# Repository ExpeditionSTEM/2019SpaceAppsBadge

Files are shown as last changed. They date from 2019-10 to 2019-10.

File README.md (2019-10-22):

# 2019SpaceAppsBadge
PLEASE STAY TUNED FOR UPDATES!  I WILL GET THIS REPO UPDATED BY 10/29.

A description of the 2019 Space Apps Trophy made for the Huntsville Main Stage

LIST OF COMPONENTS:

CUSTOM:

Custom Printed Circuit Board (PCB) - Designed by Andrew Denio. Produced by JLCPCB.com See "EAGLE" folder for files.

ATTINY 85-20PU Microcontroller 8 pin DIP: https://www.amazon.com/gp/product/B06W9JBJJ6

SSD1306 128x32 pixel i2c OLED Display https://www.amazon.com/gp/product/B07WHVYWXS/

3xAAA Enclosed Battery Case https://www.amazon.com/gp/product/B07M8RV9DC

MISC:

Photoresistor (Light Sensor) 5 mm GM5539 5539 https://www.amazon.com/dp/B01N7V536K

Slide Switch 3 Pin 2 Position SPDT with PCB Panel for Arduino 0.5 Amp, 50V DC, 2 mm https://www.amazon.com/gp/product/B079D58DB3/

FROM JLCPCB (mounted through SMT assembly):

WS2812B-V3 - 5050 LIGHT EMITTING DIODE (LED) RED/GREEN/BLUE SMD

8 pin Female Header to re-flash ATTINY chip

FOR 'THROUGH-HOLE' BOARD:

470 OHM 1/4 Watt resistor

10 KOHM 1/4 Watt resistor

6mm x 6mm Tactile Buttons

10uF 25V Capacitor

FOR 'SMD' BOARD:

TACTILE SWITCHES SPST 5.10MM X 5.10MM 0.40MM 50MA @ 12VDC SMD

Multilayer Ceramic Capacitor - SMD/SMT 10UF 25V 0805 ROHS

CHIP RESISTOR - SURFACE MOUNT 10KOHMS ±1% 1/8W 0805 ROHS

CHIP RESISTOR - SURFACE MOUNT 470OHMS ±1% 1/8W 0805 ROHS

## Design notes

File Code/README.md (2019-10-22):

This folder contains the Demo Sketch used during the 2019 Space Apps Huntsville event as well as the required libraries

The "ATTiny Core" zip file includes the Tiny NeoPixel Library

The "LCD" assistant is used to convert a bitmap to a hex table for Arduino.

The "ozoled-oled-display-096-i2c-driver-library-master.zip" library has more example for the OLED display

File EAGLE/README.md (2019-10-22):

This folder contains the Eagle and Gerber files for the Space Apps badge

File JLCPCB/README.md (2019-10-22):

This folder contains the files needed for SMT Assembly from JLCPCB.com   Build of Materials and Mounting Positions.

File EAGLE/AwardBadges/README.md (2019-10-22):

This folder contains all of the files for the 10 different award badges given out on Sunday, October 21, 2019 at Space Apps Huntsville.  

Electrically, they are all the same.  The only difference is the screen printed layer to list what type of award the badge has been given.

These badges are also electrically the same as the "MainBadgeSMD."

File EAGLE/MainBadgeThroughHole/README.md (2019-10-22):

This badge is the non-assembled version.  I will create a YouTube video at some point on how to assemble this badge.

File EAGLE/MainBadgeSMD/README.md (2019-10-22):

This is the badge that was 'fully' assembled.  Most of the badge was assembled by JLCPCB, but some components were hand soldered/mounted.

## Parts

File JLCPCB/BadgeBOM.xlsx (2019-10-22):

Comment | Designator | Footprint | LCSC Part #（optional）
10uF | C1 | 0805 | C15850
10KO | R2 | 0805 | C17414
470O | R1 | 0805 | C17710
NEOPIXEL5050 | NEO1 | LED-4_5050 | C114585
NEOPIXEL5050 | NEO2 | LED-4_5050 | C114585
NEOPIXEL5050 | NEO3 | LED-4_5050 | C114585
NEOPIXEL5050 | NEO4 | LED-4_5050 | C114585
NEOPIXEL5050 | NEO5 | LED-4_5050 | C114585
NEOPIXEL5050 | NEO6 | LED-4_5050 | C114585
NEOPIXEL5050 | NEO7 | LED-4_5050 | C114585
NEOPIXEL5050 | NEO8 | LED-4_5050 | C114585
NEOPIXEL5050 | NEO9 | LED-4_5050 | C114585
NEOPIXEL5050 | NEO10 | LED-4_5050 | C114585
BUTTON_B | BUTTON | SMD-SW-4_5.1x5.1x2.0 | C318884
BUTTON_A | RESET | SMD-SW-4_5.1x5.1x2.0 | C318884

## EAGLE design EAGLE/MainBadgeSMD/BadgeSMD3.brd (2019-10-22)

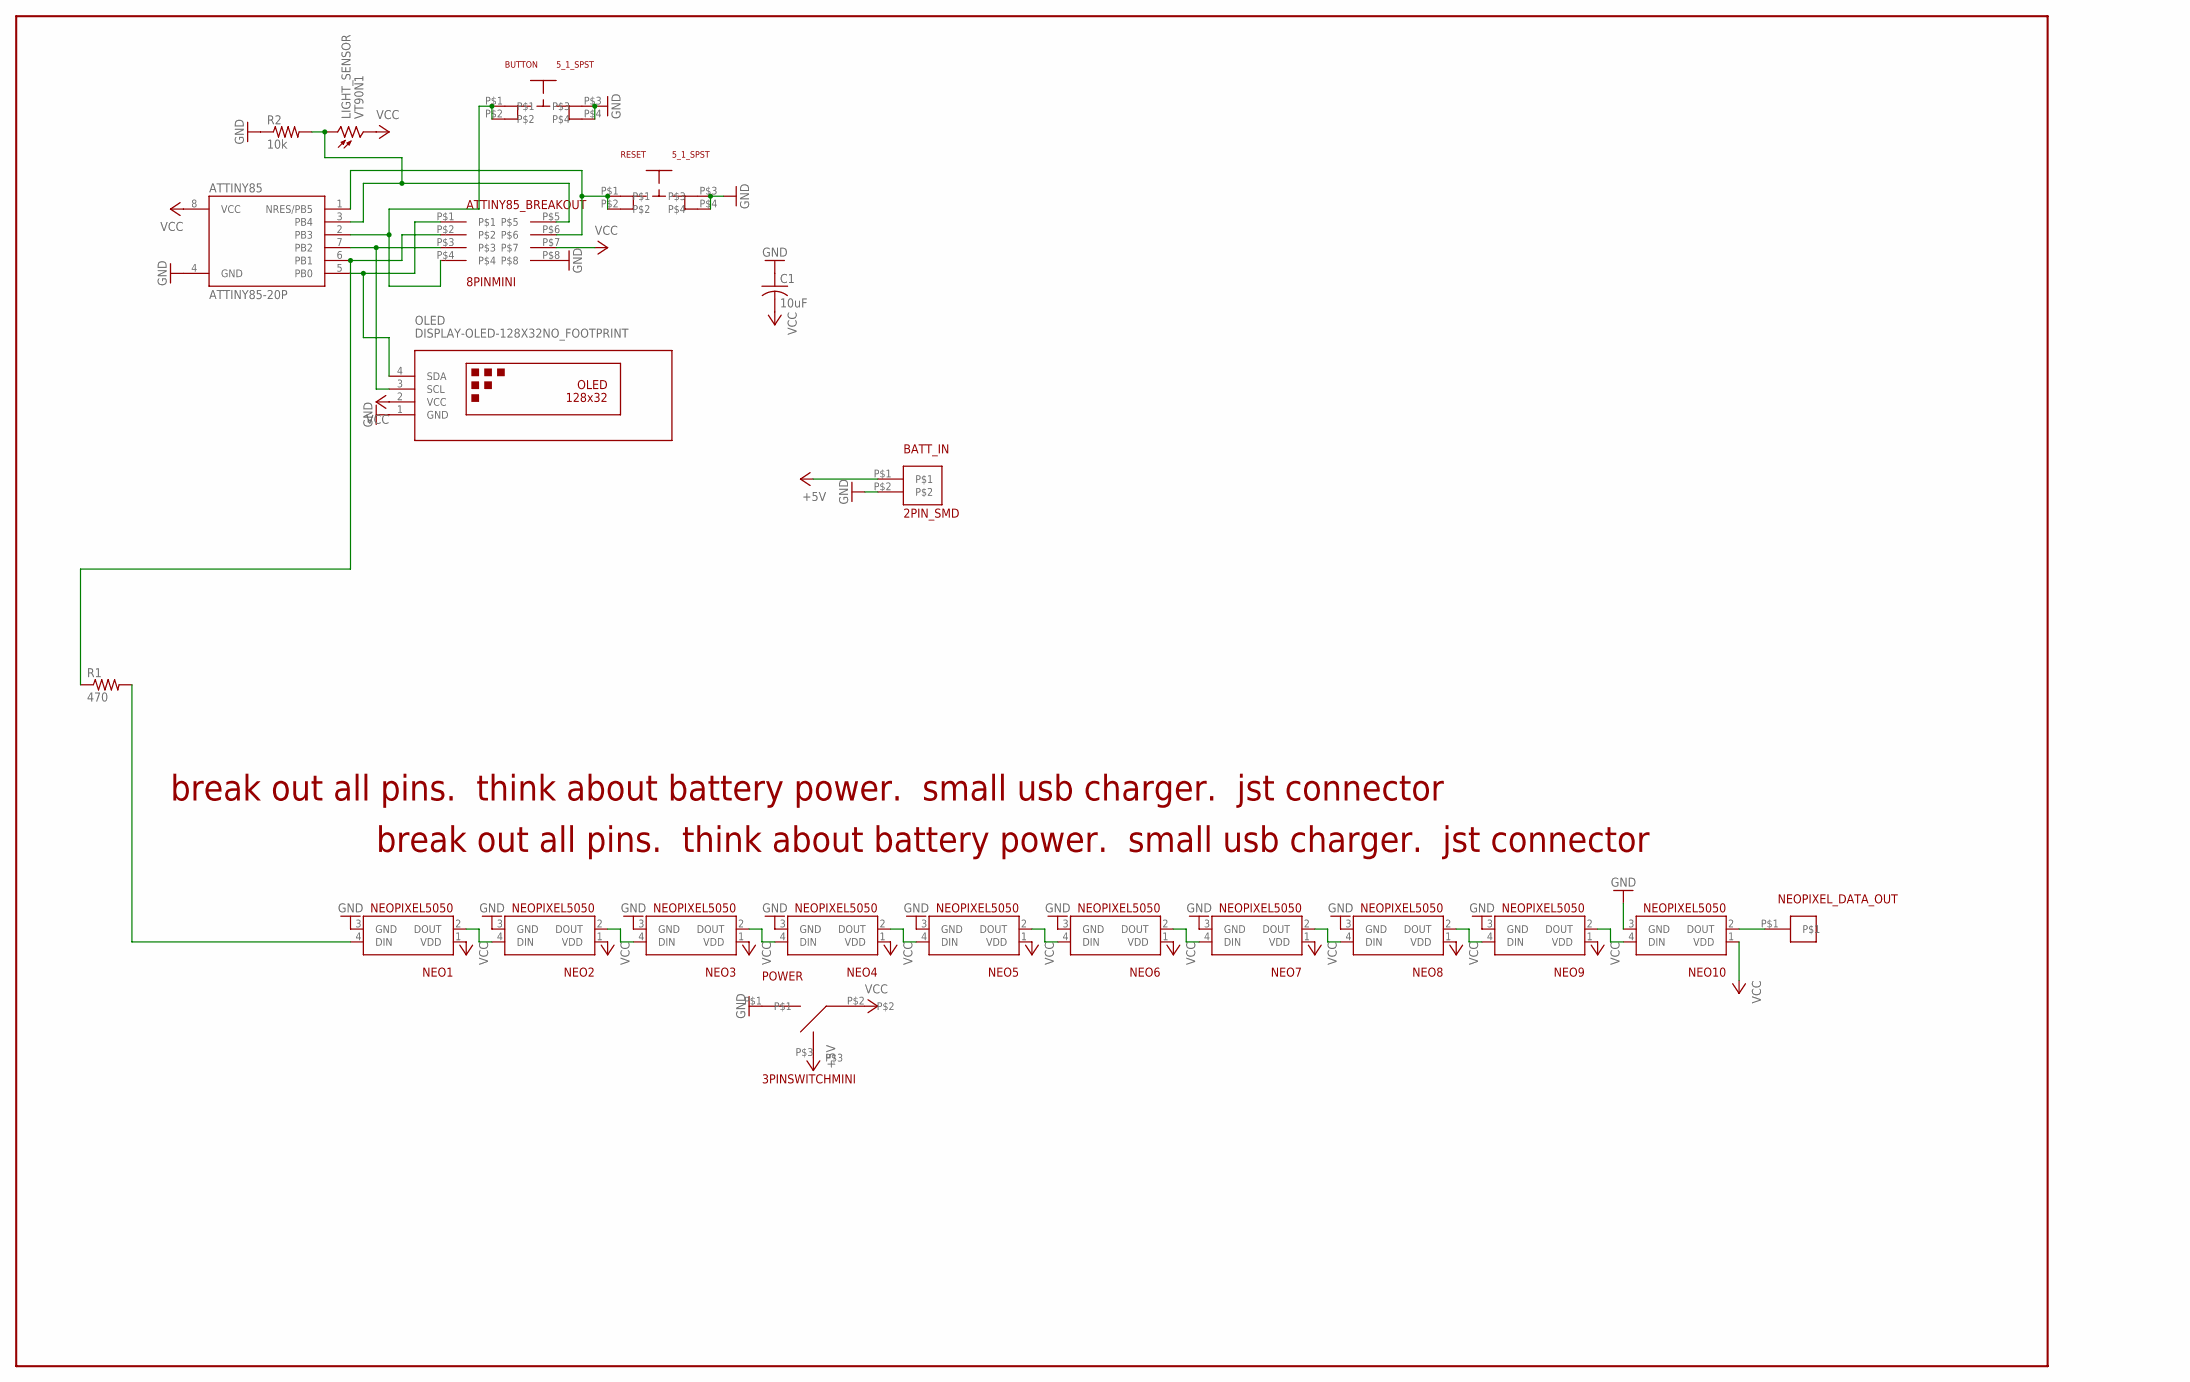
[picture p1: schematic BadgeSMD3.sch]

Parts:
ATTINY85: ATTINY85-20P; PDIP08_300MIL
ATTINY85_BREAKOUT: 8PINMINI
BATT_IN: 2PIN_SMD
BUTTON: 5_1_SPST
C1: 10uF; C0805
LIGHT_SENSOR: VT90N1; VT900
NEO1, NEO2, NEO3, NEO4, NEO5, NEO6, NEO7, NEO8, NEO9, NEO10: NEOPIXEL5050
NEOPIXEL_DATA_OUT: 1PINMINI
OLED: DISPLAY-OLED-128X32NO_FOOTPRINT; DISPLAY-OLED-128X32_NO_FOOTPRINT
POWER: 3PINSWITCHMINI; 3PINMINI
R1: 470; M0805
R2: 10k; M0805
RESET: 5_1_SPST

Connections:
+5V: BATT_IN.P$1, POWER.P$3
GND: ATTINY85.4 (GND), ATTINY85_BREAKOUT.P$8, BATT_IN.P$2, BUTTON.P$3, BUTTON.P$4, C1.1, NEO1.3 (GND), NEO2.3 (GND), NEO3.3 (GND), NEO4.3 (GND), NEO5.3 (GND), NEO6.3 (GND), NEO7.3 (GND), NEO8.3 (GND), NEO9.3 (GND), NEO10.3 (GND), OLED.1 (GND), POWER.P$1, R2.1, RESET.P$3, RESET.P$4
unnamed: ATTINY85.5 (PB0), ATTINY85_BREAKOUT.P$1, OLED.4 (SDA)
unnamed: NEO1.4 (DIN), R1.2
unnamed: ATTINY85.7 (PB2), ATTINY85_BREAKOUT.P$3, OLED.3 (SCL)
unnamed: ATTINY85.2 (PB3), ATTINY85_BREAKOUT.P$4, BUTTON.P$1, BUTTON.P$2
unnamed: ATTINY85.3 (PB4), ATTINY85_BREAKOUT.P$5, LIGHT_SENSOR.1, R2.2
unnamed: ATTINY85.1 (NRES/PB5), ATTINY85_BREAKOUT.P$6, RESET.P$1, RESET.P$2
unnamed: NEO1.2 (DOUT), NEO2.4 (DIN)
unnamed: ATTINY85.6 (PB1), ATTINY85_BREAKOUT.P$2, R1.1
unnamed: NEO2.2 (DOUT), NEO3.4 (DIN)
unnamed: NEO3.2 (DOUT), NEO4.4 (DIN)
unnamed: NEO4.2 (DOUT), NEO5.4 (DIN)
unnamed: NEO5.2 (DOUT), NEO6.4 (DIN)
unnamed: NEO6.2 (DOUT), NEO7.4 (DIN)
unnamed: NEO7.2 (DOUT), NEO8.4 (DIN)
unnamed: NEO8.2 (DOUT), NEO9.4 (DIN)
unnamed: NEO9.2 (DOUT), NEO10.4 (DIN)
unnamed: NEO10.2 (DOUT), NEOPIXEL_DATA_OUT.P$1
VCC: ATTINY85.8 (VCC), ATTINY85_BREAKOUT.P$7, C1.2, LIGHT_SENSOR.2, NEO1.1 (VDD), NEO2.1 (VDD), NEO3.1 (VDD), NEO4.1 (VDD), NEO5.1 (VDD), NEO6.1 (VDD), NEO7.1 (VDD), NEO8.1 (VDD), NEO9.1 (VDD), NEO10.1 (VDD), OLED.2 (VCC), POWER.P$2

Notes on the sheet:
break out all pins. think about battery power. small usb charger. jst connector

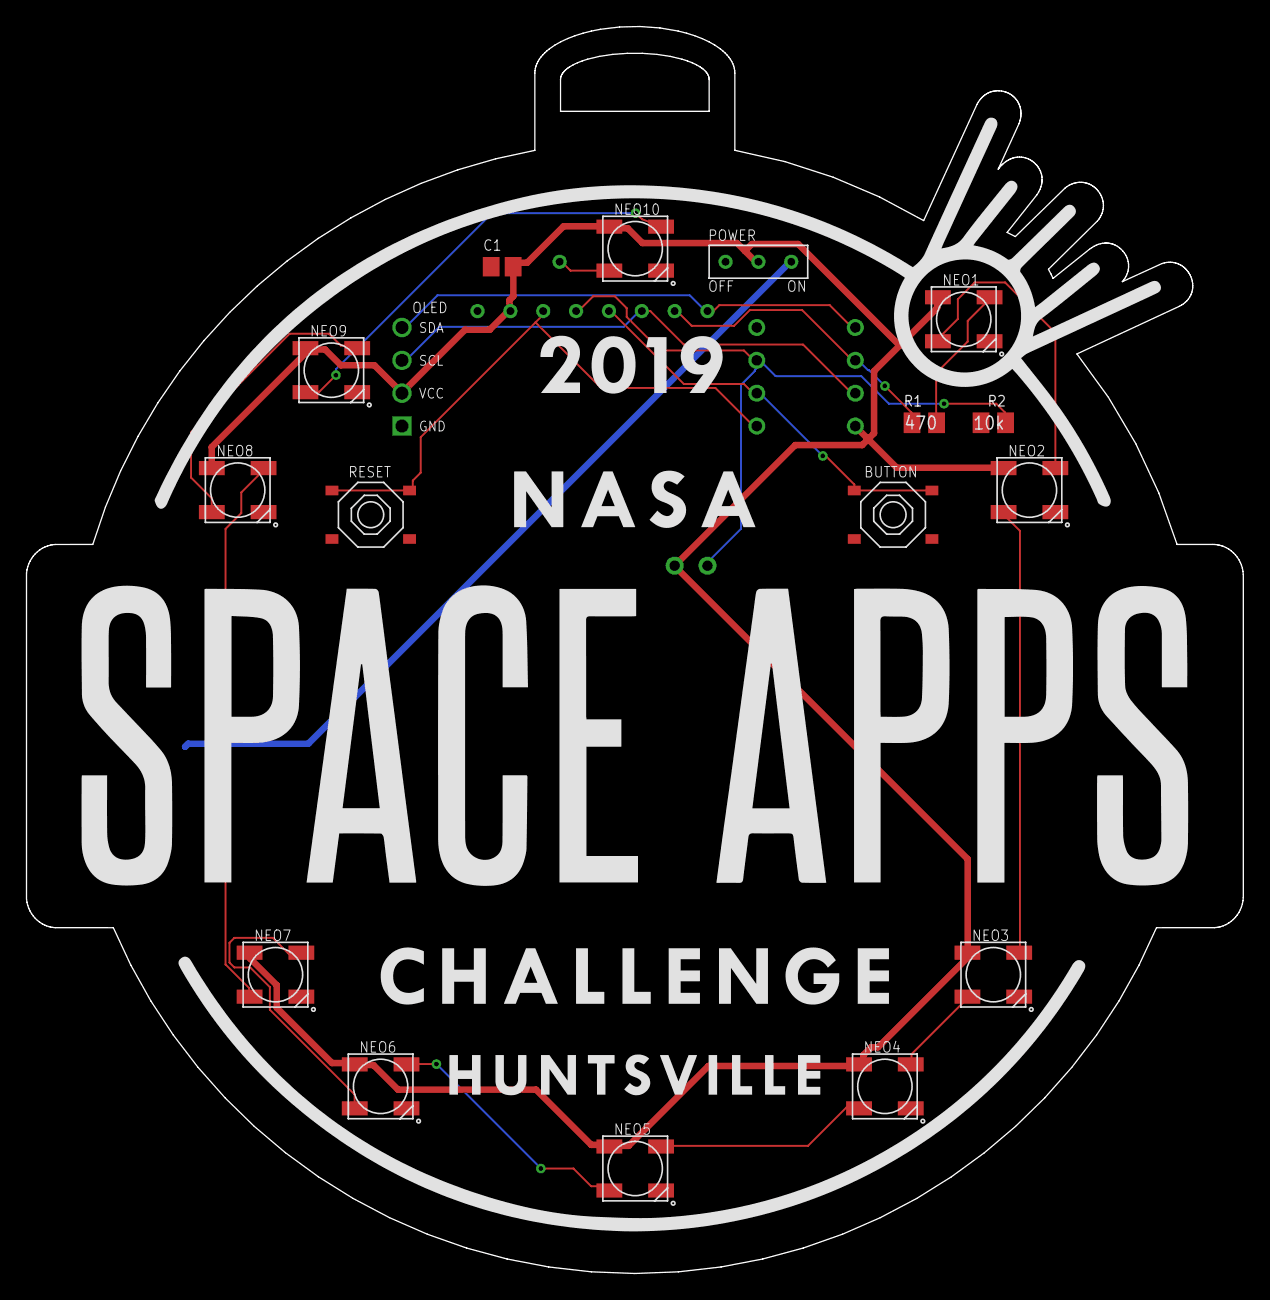
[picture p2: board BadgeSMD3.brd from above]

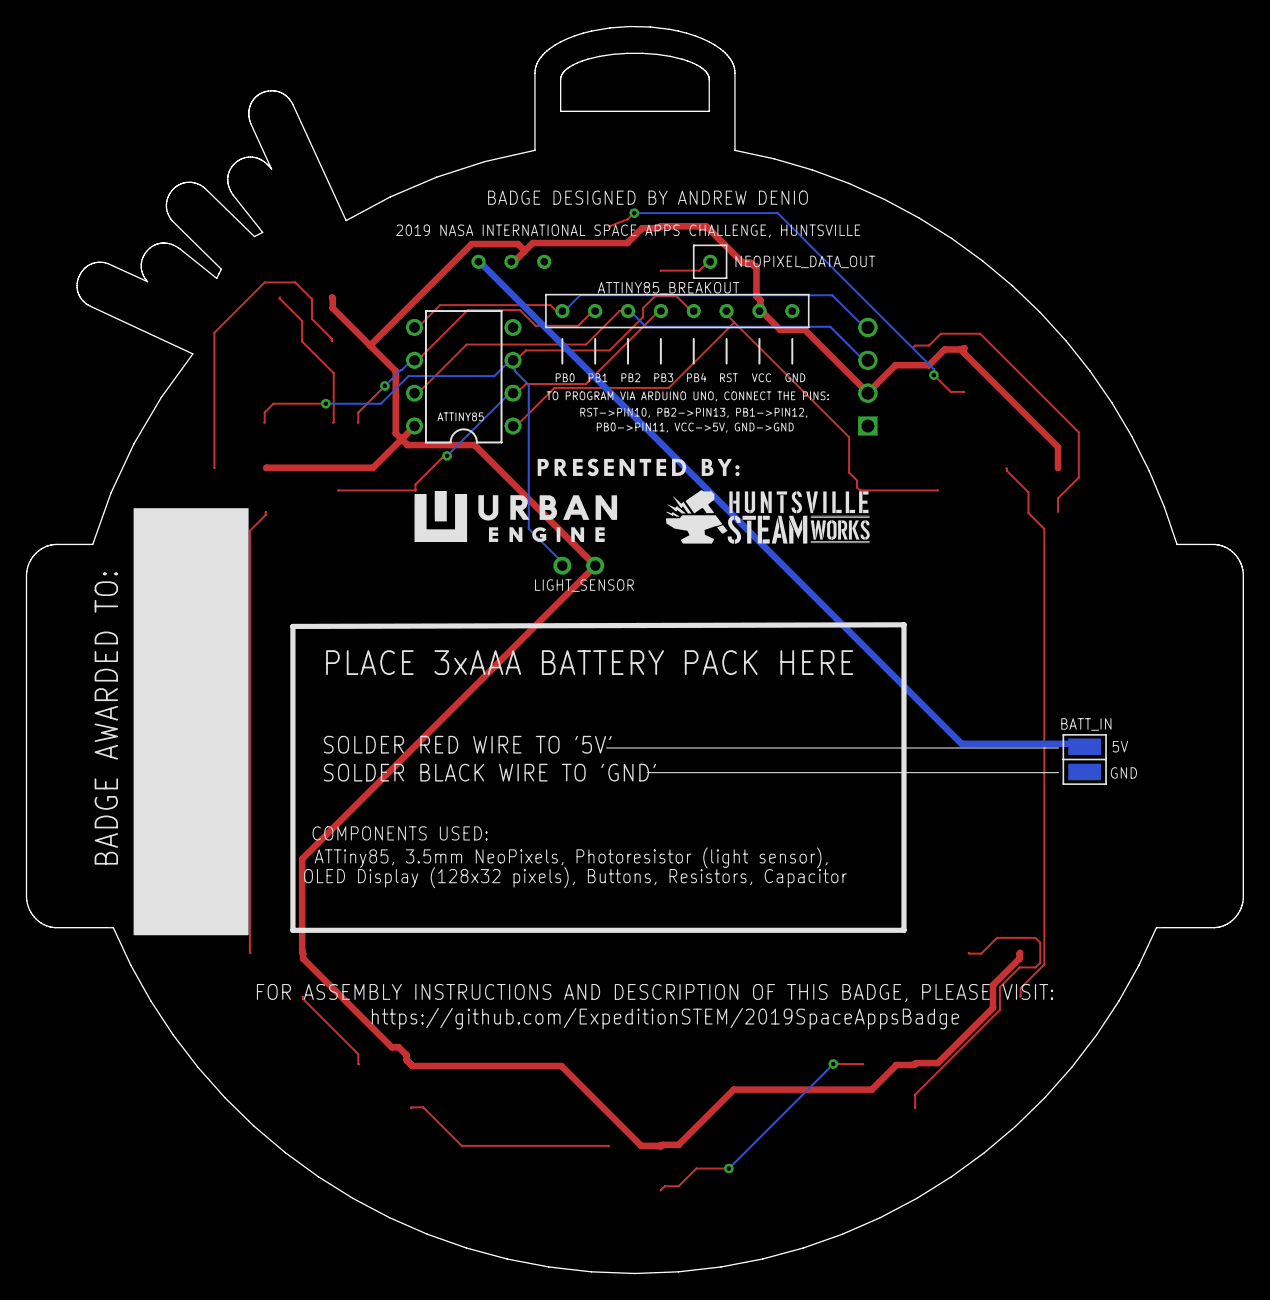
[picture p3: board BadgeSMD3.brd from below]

Board: 2 copper layers, 94.1 x 96.4 mm, 22 parts (5 on the bottom side), 20 nets.

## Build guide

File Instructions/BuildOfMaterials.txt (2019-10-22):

2019 Space Apps Through-Hole Badge
Build of Materials

Because some of these components are really small, it would be in everyone's financial interest to try and source these parts as a team, because you only need a few of each.
The links below are suggestions and you may be able to find a better deal somewhere else.

1x Custom Printed Circuit Board (PCB).  
Provided at Space Apps

1x ATTINY 85-20PU Microcontroller 8 pin DIP (comes in 5-pack): 
https://www.amazon.com/gp/product/B06W9JBJJ6

1x SSD1306 128x32 pixel i2c OLED Display (comes in 2-pack) 
https://www.amazon.com/gp/product/B07WHVYWXS/

1x 3xAAA Enclosed Battery Case (comes in 6 pack) 
https://www.amazon.com/gp/product/B07M8RV9DC

1x  Photoresistor (Light Sensor) 5 mm GM5539 5539 (30 pack) 
https://www.amazon.com/dp/B01N7V536K

1x Slide Switch 3 Pin 2 Position SPDT with PCB Panel for Arduino 0.5 Amp, 50V DC, 2 mm (50 pack) 
https://www.amazon.com/gp/product/B079D58DB3/

10x WS2812B- 5050 LIGHT EMITTING DIODE (LED) RED/GREEN/BLUE SMD (NEOPIXELS)
https://www.amazon.com/ACROBOTIC-10-Pack-WS2812B-Arduino-Raspberry/dp/B07RYP2WVY/
https://www.amazon.com/Led-World-WS2812B-Individually-Addressable/dp/B00YC7ZXRM
https://www.adafruit.com/product/1655
https://www.adafruit.com/product/3094

1x 8 pin Female Header to Flash ATTINY chip 
https://www.amazon.com/Glarks-Straight-Connector-Assortment-Prototype/dp/B076GZXW3Z

1x 470 OHM 1/4 Watt resistor
https://www.amazon.com/AUSTOR-Resistors-Assortment-Resistor-Experiments/dp/B07BKRS4QZ/

1x 10 KOHM 1/4 Watt resistor
https://www.amazon.com/AUSTOR-Resistors-Assortment-Resistor-Experiments/dp/B07BKRS4QZ/

2x 6mm x 6mm Tactile Buttons   
https://www.amazon.com/Momentary-Tactile-Button-Switch-black/dp/B0796QHL5Z/

1x 10uF 25V Capacitor
https://www.amazon.com/gp/product/B01MSQOX0Q/

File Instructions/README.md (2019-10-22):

INSTRUCTIONS

I have provided the Demo Code / sketch used during the 2019 Space Apps Huntsville event. 

I will upload a YouTube video of how to use the demo sketch on the trophy when I get a chance.

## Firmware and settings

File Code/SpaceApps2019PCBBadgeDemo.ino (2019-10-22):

////////////////////////////////////////////////////////////////
//////////  2019 SPACE APPS HUNTSVILLE - PCB BADGE DEMO CODE - BY ANDREW DENIO 
////////////////////////////////////////////////////////////////

/*
  THIS CODE WAS USED TO DEMO THE BADGE FOR 2019 SPACE APPS CHALLENGE EVENT IN HUNTSVILLE.

  ALL LIBRARIES FOR COMPONENTS WILL BE INCLUDED IN GITHUB LINK, SO FEEL FREE TO TINKER AROUND!
  https://github.com/ExpeditionSTEM/2019SpaceAppsBadge

  LIBRARIES FOR NEOPIXELS WERE DERIVED FROM LIBRARIES BY ADAFRUIT

  Adafruit invests time and resources providing this open source code,
  please support Adafruit and open-source hardware by purchasing
  products from Adafruit!
  Written by Limor Fried/Ladyada for Adafruit Industries.
  MIT license, all text above must be included in any redistribution
  
 */


////////////////////////////////////////////////////////////////
//////////  ATTINY 85 PINOUT
////////////////////////////////////////////////////////////////

 
/*
  
  GND - BATTERY NEGATIVE TERMINAL
  VCC - BATTERY POSITIVE TERMINAL
  PBO - I2C BUS - SDA
  PB1 - NEOPIXEL OUT
  PB2 - I2C BUS - SCL
  PB3 - BUTTON INPUT
  PB4 - LIGHT SENSOR INPUT
  PB5 - RESET BUTTON
  
 */


////////////////////////////////////////////////////////////////
//////////  VARIABLES AND LIBRARIES
////////////////////////////////////////////////////////////////

#include "TinyWireM.h" // USED FOR I2C CAPABILITIES
#include "TinyOzOLED.h" // USED FOR THE SSD1306 OLED SCREEN

#include <tinyNeoPixel_Static.h>  // USED FOR NEOPIXELS
#define PIN 1
// Parameter 1 = number of pixels in strip
// Parameter 2 = Arduino pin number (most are valid)
// Parameter 3 = pixel type flags, add together as needed:
//   NEO_GRB     Pixels are wired for GRB bitstream (most NeoPixel products)
//   NEO_RGB     Pixels are wired for RGB bitstream (v1 FLORA pixels, not v2)
// Parameter 4 = array to store pixel data in      
#define NUMPIXELS 10
// Since this is for the static version of the library, we need to supply the pixel array
// This saves space by eliminating use of malloc() and free(), and makes the RAM used for
// the frame buffer show up when the sketch is compiled.
byte pixels[NUMPIXELS * 3];
// When we setup the NeoPixel library, we tell it how many pixels, and which pin to use to send signals.
// Note that for older NeoPixel strips you might need to change the third parameter--see the strandtest
// example for more information on possible values. Finally, for the 4th argument we pass the array we
// defined above.
tinyNeoPixel strip = tinyNeoPixel(NUMPIXELS, PIN, NEO_GRB, pixels);
// IMPORTANT: To reduce NeoPixel burnout risk, add 1000 uF capacitor across
// pixel power leads, add 300 - 500 Ohm resistor on first pixel's data input
// and minimize distance between Arduino and first pixel.  Avoid connecting
// on a live circuit...if you must, connect GND first.


#define BUTTON_PIN   3    // Digital IO pin connected to the button.  This will be
                          // driven with a pull-up resistor so the switch should
                          // pull the pin to ground momentarily.  On a high -> low
                          // transition the button press logic will execute.

                          

#define LIGHT_SENSOR_PIN A2  // THIS IS PB4, BUT MUST LABEL IT A2 IN ORDER FOR THE ANALOG FUNCTIONS TO WORK
int lightSensorValue = 0;



//THIS IS THE BITMAP OUTPUT TO DISPLAY THE SPACE APPS LOGO ON STARTUP
const unsigned char spaceapps [] PROGMEM = {
0x00, 0x00, 0x00, 0x00, 
0x00, 0x00, 0x00, 0x00, 0x00, 0x00, 0x00, 0x00, 0x00, 0x00, 0x00, 0xC0, 0xF0, 0x18, 0x08, 0x0C,
0x08, 0x38, 0xF0, 0x00, 0x00, 0x00, 0x00, 0xF8, 0xF8, 0x18, 0x18, 0x18, 0x18, 0x18, 0xF0, 0x00,
0x00, 0x00, 0x00, 0x00, 0xE0, 0xF8, 0xF8, 0x80, 0x00, 0x00, 0x00, 0x00, 0x00, 0x00, 0xF0, 0x18,
0x08, 0x0C, 0x08, 0x18, 0xF0, 0x00, 0x00, 0x00, 0x00, 0xF8, 0xF8, 0x18, 0x18, 0x18, 0x18, 0x18,
0x00, 0x00, 0x00, 0x00, 0x00, 0x00, 0x00, 0x00, 0x00, 0x00, 0x00, 0x80, 0xF8, 0xF8, 0xE0, 0x00,
0x00, 0x00, 0x00, 0x00, 0x00, 0xF8, 0xF8, 0x18, 0x18, 0x18, 0x18, 0x18, 0xF0, 0xC0, 0x00, 0x00,
0x00, 0xF8, 0xF8, 0x18, 0x18, 0x18, 0x18, 0x18, 0xF0, 0x00, 0x00, 0x00, 0x00, 0xF0, 0xF8, 0x08,
0x08, 0x08, 0x18, 0xF8, 0x00, 0x00, 0x00, 0x00, 0x00, 0x00, 0x00, 0x00, 0x00, 0x00, 0x00, 0x00,
0x00, 0x00, 0x00, 0x00, 0x00, 0x00, 0x00, 0x00, 0x00, 0x00, 0x00, 0x0F, 0x3F, 0xE0, 0xC0, 0x80,
0x00, 0x00, 0x07, 0x00, 0x00, 0x00, 0x00, 0xFF, 0xFF, 0x80, 0x80, 0x80, 0x80, 0xC0, 0x7F, 0x00,
0x00, 0x00, 0x00, 0xE0, 0xFF, 0x01, 0x07, 0xFF, 0xC0, 0x00, 0x00, 0x00, 0x00, 0x00, 0xFF, 0x00,
0x00, 0x00, 0x00, 0x00, 0x07, 0x00, 0x00, 0x00, 0x00, 0xFF, 0xFF, 0x80, 0x80, 0x80, 0x00, 0x00,
0x00, 0x00, 0x00, 0x00, 0x00, 0x00, 0x00, 0x00, 0x00, 0x00, 0xC0, 0xFF, 0x03, 0x01, 0xFF, 0xF0,
0x00, 0x00, 0x00, 0x00, 0x00, 0xFF, 0xFF, 0x80, 0x80, 0x80, 0x80, 0xC0, 0xFF, 0x3F, 0x00, 0x00,
0x00, 0xFF, 0xFF, 0x80, 0x80, 0x80, 0x80, 0xC0, 0xFF, 0x06, 0x00, 0x00, 0x00, 0x3F, 0x7F, 0xC0,
0x80, 0x00, 0x00, 0x07, 0x00, 0x00, 0x00, 0x00, 0x00, 0x00, 0x00, 0x00, 0x00, 0x00, 0x00, 0x00,
0x00, 0x00, 0x00, 0x00, 0x00, 0x00, 0x00, 0x00, 0x00, 0x00, 0x00, 0xE0, 0xE0, 0x00, 0x01, 0x03,
0x07, 0x1C, 0xF8, 0x00, 0x00, 0x00, 0x00, 0xFF, 0xFF, 0x01, 0x01, 0x01, 0x01, 0x00, 0x00, 0x00,
0x00, 0x00, 0xF0, 0xFF, 0x00, 0x00, 0x00, 0x07, 0xFF, 0xC0, 0x00, 0x00, 0x00, 0x00, 0xFF, 0x00,
0x00, 0x00, 0x00, 0x00, 0xE0, 0x00, 0x00, 0x00, 0x00, 0xFF, 0xFF, 0x01, 0x01, 0x01, 0x00, 0x00,
0x00, 0x00, 0x00, 0x00, 0x00, 0x00, 0x00, 0x00, 0x00, 0xC0, 0xFF, 0x03, 0x00, 0x00, 0x01, 0xFF,
0xF0, 0x00, 0x00, 0x00, 0x00, 0xFF, 0xFF, 0x01, 0x01, 0x01, 0x01, 0x00, 0x00, 0x00, 0x00, 0x00,
0x00, 0xFF, 0xFF, 0x01, 0x01, 0x01, 0x01, 0x00, 0x00, 0x00, 0x00, 0x00, 0x00, 0xE0, 0x00, 0x00,
0x01, 0x03, 0x0E, 0xFC, 0xE0, 0x00, 0x00, 0x00, 0x00, 0x00, 0x00, 0x00, 0x00, 0x00, 0x00, 0x00,
0x00, 0x00, 0x00, 0x00, 0x00, 0x00, 0x00, 0x00, 0x00, 0x00, 0x00, 0x07, 0x3F, 0x30, 0x20, 0x20,
0x20, 0x38, 0x1F, 0x00, 0x00, 0x00, 0x00, 0x3F, 0x3F, 0x00, 0x00, 0x00, 0x00, 0x00, 0x00, 0x00,
0x00, 0x38, 0x3F, 0x03, 0x03, 0x03, 0x03, 0x03, 0x07, 0x3F, 0x00, 0x00, 0x00, 0x00, 0x1F, 0x30,
0x20, 0x60, 0x20, 0x30, 0x1F, 0x00, 0x00, 0x00, 0x00, 0x3F, 0x3F, 0x20, 0x20, 0x20, 0x20, 0x20,
0x00, 0x00, 0x00, 0x00, 0x00, 0x00, 0x00, 0x00, 0x20, 0x3F, 0x03, 0x01, 0x01, 0x01, 0x01, 0x03,
0x3F, 0x30, 0x00, 0x00, 0x00, 0x3F, 0x3F, 0x00, 0x00, 0x00, 0x00, 0x00, 0x00, 0x00, 0x00, 0x00,
0x00, 0x3F, 0x3F, 0x00, 0x00, 0x00, 0x00, 0x00, 0x00, 0x00, 0x00, 0x00, 0x00, 0x1F, 0x38, 0x20,
0x20, 0x20, 0x30, 0x3F, 0x07, 0x00, 0x00, 0x00, 0x00, 0x00, 0x00, 0x00, 0x00, 0x00, 0x00, 0x00
};

//THIS IS THE BITMAP OUTPUT TO DISPLAY THE NASA WORM LOGO DURING MENU 
const unsigned char nasabitmap [] PROGMEM = {
0x00, 0x00, 0x00, 0x00, 
0x00, 0x00, 0x00, 0x00, 0x00, 0x00, 0x00, 0x00, 0x00, 0x00, 0x00, 0x00, 0x00, 0x00, 0x00, 0x00,
0x00, 0x00, 0x00, 0x00, 0x00, 0x00, 0x80, 0xC0, 0xE0, 0xE0, 0xE0, 0xE0, 0xE0, 0xE0, 0xC0, 0x80,
0x00, 0x00, 0x00, 0x00, 0x00, 0x00, 0x00, 0x00, 0xE0, 0xE0, 0xE0, 0xE0, 0x00, 0x00, 0x00, 0x00,
0x00, 0x00, 0x80, 0xC0, 0xE0, 0xE0, 0xE0, 0xF0, 0xE0, 0xE0, 0xC0, 0x80, 0x00, 0x00, 0x00, 0x00,
0x00, 0x00, 0x00, 0x80, 0xC0, 0xC0, 0xE0, 0xE0, 0xE0, 0xE0, 0xE0, 0xE0, 0xE0, 0xE0, 0xE0, 0xE0,
0xE0, 0xE0, 0xE0, 0xE0, 0x00, 0x00, 0x00, 0x00, 0x00, 0x00, 0x00, 0x80, 0xC0, 0xE0, 0xE0, 0xF0,
0xE0, 0xE0, 0xE0, 0xC0, 0x80, 0x00, 0x00, 0x00, 0x00, 0x00, 0x00, 0x00, 0x00, 0x00, 0x00, 0x00,
0x00, 0x00, 0x00, 0x00, 0x00, 0x00, 0x00, 0x00, 0x00, 0x00, 0x00, 0x00, 0x00, 0x00, 0x00, 0x00,
0x00, 0x00, 0x00, 0x00, 0x00, 0x00, 0x00, 0x00, 0x00, 0x00, 0x00, 0x00, 0x00, 0x00, 0x00, 0x00,
0x00, 0x00, 0x00, 0x00, 0x00, 0xFC, 0xFF, 0xFF, 0xFF, 0x03, 0x01, 0x01, 0x01, 0x0F, 0xFF, 0xFF,
0xFE, 0xF0, 0x00, 0x00, 0x00, 0x00, 0x00, 0x00, 0xFF, 0xFF, 0xFF, 0xFF, 0x00, 0x00, 0x00, 0x00,
0xE0, 0xFC, 0xFF, 0xFF, 0x1F, 0x03, 0x01, 0x01, 0x01, 0x0F, 0x7F, 0xFF, 0xFF, 0xF8, 0xC0, 0x00,
0x00, 0x00, 0x7E, 0xFF, 0xFF, 0xFF, 0xC3, 0xC1, 0xC1, 0xC1, 0xC1, 0xC1, 0xC1, 0xC1, 0xC1, 0x81,
0x81, 0x81, 0x01, 0x01, 0x00, 0x00, 0x00, 0x00, 0x80, 0xF8, 0xFF, 0xFF, 0x7F, 0x0F, 0x01, 0x01,
0x01, 0x03, 0x1F, 0xFF, 0xFF, 0xFC, 0xE0, 0x00, 0x00, 0x00, 0x00, 0x00, 0x00, 0x00, 0x00, 0x00,
0x00, 0x00, 0x00, 0x00, 0x00, 0x00, 0x00, 0x00, 0x00, 0x00, 0x00, 0x00, 0x00, 0x00, 0x00, 0x00,
0x00, 0x00, 0x00, 0x00, 0x00, 0x00, 0x00, 0x00, 0x00, 0x00, 0x00, 0x00, 0x00, 0x00, 0x00, 0x00,
0x00, 0x00, 0x00, 0x00, 0x00, 0xFF, 0xFF, 0xFF, 0xFF, 0x00, 0x00, 0x00, 0x00, 0x00, 0x00, 0x0F,
0x7F, 0xFF, 0xFF, 0xF0, 0x80, 0x00, 0x00, 0x00, 0xFF, 0xFF, 0xFF, 0xFF, 0x00, 0xC0, 0xF8, 0xFF,
0xFF, 0x7F, 0x0F, 0x00, 0x00, 0x00, 0x00, 0x00, 0x00, 0x00, 0x00, 0x03, 0x1F, 0xFF, 0xFF, 0xFC,
0xE0, 0x00, 0x00, 0x00, 0x01, 0x03, 0x03, 0x03, 0x07, 0x07, 0x07, 0x07, 0x07, 0x07, 0x07, 0x07,
0x8F, 0xFF, 0xFF, 0xFE, 0x78, 0x00, 0xE0, 0xFC, 0xFF, 0xFF, 0x1F, 0x03, 0x00, 0x00, 0x00, 0x00,
0x00, 0x00, 0x00, 0x00, 0x07, 0x3F, 0xFF, 0xFF, 0xF8, 0xC0, 0x00, 0x00, 0x00, 0x00, 0x00, 0x00,
0x00, 0x00, 0x00, 0x00, 0x00, 0x00, 0x00, 0x00, 0x00, 0x00, 0x00, 0x00, 0x00, 0x00, 0x00, 0x00,
0x00, 0x00, 0x00, 0x00, 0x00, 0x00, 0x00, 0x00, 0x00, 0x00, 0x00, 0x00, 0x00, 0x00, 0x00, 0x00,
0x00, 0x00, 0x00, 0x00, 0x00, 0x0F, 0x0F, 0x0F, 0x0F, 0x00, 0x00, 0x00, 0x00, 0x00, 0x00, 0x00,
0x00, 0x03, 0x07, 0x0F, 0x0F, 0x0F, 0x0F, 0x0F, 0x0F, 0x07, 0x03, 0x00, 0x0C, 0x0F, 0x0F, 0x0F,
0x03, 0x00, 0x00, 0x00, 0x00, 0x00, 0x00, 0x00, 0x00, 0x00, 0x00, 0x00, 0x00, 0x00, 0x07, 0x0F,
0x0F, 0x0F, 0x0F, 0x0F, 0x0F, 0x0F, 0x0F, 0x0F, 0x0F, 0x0F, 0x0F, 0x0F, 0x0F, 0x0F, 0x0F, 0x0F,
0x07, 0x07, 0x03, 0x01, 0x08, 0x0F, 0x0F, 0x0F, 0x07, 0x00, 0x00, 0x00, 0x00, 0x00, 0x00, 0x00,
0x00, 0x00, 0x00, 0x00, 0x00, 0x00, 0x03, 0x0F, 0x0F, 0x0F, 0x0E, 0x00, 0x00, 0x00, 0x00, 0x00,
0x00, 0x00, 0x00, 0x00, 0x00, 0x00, 0x00, 0x00, 0x00, 0x00, 0x00, 0x00, 0x00, 0x00, 0x00, 0x00
};

// MENU VARIABLES
int NewMenuVar = 1;
int MenuCount = 9;
int OldMenuVar = MenuCount + 1; 

// BUTTON VARIABLES
bool newState;
bool oldState = HIGH;


////////////////////////////////////////////////////////////////
//////////  SETUP LOOP
////////////////////////////////////////////////////////////////

void setup() {

  //Initialize pins
  pinMode(BUTTON_PIN, INPUT_PULLUP);
  pinMode(LIGHT_SENSOR_PIN, INPUT);
  pinMode(PIN,OUTPUT); //set pin output - this is not done internally by the library for Static version of library

  //Start Neopixels
  //strip.begin(); //Static version does not use this.
  strip.show(); // Initialize all pixels to 'off'

  //Start Screen.  Some of these settings are to get the screen in the right orientation.
  OzOled.init();                 
  OzOled.clearDisplay(); 
  OzOled.setNormalDisplay();  
  OzOled.sendCommand(0xA1);
  OzOled.sendCommand(0xC8);
  OzOled.setHorizontalMode(); 
  OzOled.setBrightness(255);    

  //Draw the SPACE APPS logo
  OzOled.drawBitmap(spaceapps, 0, 0, 16, 8);

  delay(1000);

  OzOled.clearDisplay();  
}


////////////////////////////////////////////////////////////////
//////////  MAIN LOOP
////////////////////////////////////////////////////////////////

void loop() {

  // Check the button for activity
  DoButton();

  // Change the menu if button has been pushed
  MenuChange();

  //Reinitialize menu variables
  OldMenuVar = NewMenuVar;

}


////////////////////////////////////////////////////////////////
//////////  OTHER FUNCTIONS
////////////////////////////////////////////////////////////////


void DoButton(){

    // Get current button state.
  newState = digitalRead(BUTTON_PIN);

  // Check if state changed from high to low (button press).
  if (newState == LOW && oldState == HIGH) {
    // Short delay to debounce button.
    delay(20);
    // Check if button is still low after debounce.
    newState = digitalRead(BUTTON_PIN);
    if (newState == LOW) {
      NewMenuVar = OldMenuVar + 1;
      OzOled.clearDisplay();  
    }
    else {
      NewMenuVar = OldMenuVar;
    }
    if (NewMenuVar == MenuCount+1) {
       NewMenuVar = 1;
       }      
  }

  // Set the last button state to the old state.
  oldState = newState;

}

///////////////////////////////////////////////////////////////////////////////////////////////////////////////////

void MenuChange() {
  
         if (NewMenuVar == MenuCount+1) {
              NewMenuVar = 1;
             }
         
         if (NewMenuVar == 0) {
            NewMenuVar = MenuCount;
          }
      
        if (NewMenuVar == 1)
          {
              OzOled.setCursorXY(0,0);   
              OzOled.printString(" MAIN MENU");  
              OzOled.setCursorXY(0,2);  
              OzOled.printString(" PRESS BUTTON TO ");  
              OzOled.setCursorXY(0,3);  
              OzOled.printString(" TEST COMPONENTS "); 
              //rainbow(20);
          } 
        else if (NewMenuVar == 2)
          {
            if (newState == LOW){
              OzOled.setCursorXY(0,2);   
              OzOled.printString(" SHOWING BITMAP ");
              delay(1000);
            }
            else {
              //OzOled.setCursorXY(0,0);   
              //OzOled.printString(" HIGH ");
              showBitmap();
            }
          }     
        else if (NewMenuVar == 3)
          {
            showLightSensor();
          }  
         else if (NewMenuVar == 4)
          {
            OzOled.setCursorXY(0,0);   
            OzOled.printString(" NEOPIXEL ");
            OzOled.setCursorXY(0,2);   
            OzOled.printString(" COLOR WIPE ");
            if (newState == LOW){
              colorWipe(strip.Color(0, 0, 0), 0);    // Black/off
              colorWipe(strip.Color(255, 0, 0), 50);  // Red
              colorWipe(strip.Color(0, 0, 0), 50);    // Black/off
              colorWipe(strip.Color(0, 255, 0), 50);  // Green
              colorWipe(strip.Color(0, 0, 0), 50);    // Black/off
              colorWipe(strip.Color(0, 0, 255), 50);  // Blue
              colorWipe(strip.Color(0, 0, 0), 50);    // Black/off
              colorWipe(strip.Color(255, 255, 255), 50);  // Blue
              colorWipe(strip.Color(0, 0, 0), 0);    // Black/off
            }
            else {
              colorWipe(strip.Color(0, 0, 0), 0); //off
            }
          }                 
          else if (NewMenuVar == 5)
          {
            OzOled.setCursorXY(0,0);   
            OzOled.printString(" NEOPIXEL ");
            OzOled.setCursorXY(0,2);   
            OzOled.printString(" THEATER CHASE ");
            if (newState == LOW){
              colorWipe(strip.Color(0, 0, 0), 0);    // Black/off
              theaterChase(strip.Color(127, 127, 127), 50); // White
              colorWipe(strip.Color(0, 0, 0), 0);    // Black/off
              theaterChase(strip.Color(127,   0,   0), 50); // Red
              colorWipe(strip.Color(0, 0, 0), 0);    // Black/off
              theaterChase(strip.Color(  0,   0, 127), 50); // Blue
              colorWipe(strip.Color(0, 0, 0), 0);    // Black/off
            }
            else {
              colorWipe(strip.Color(0, 0, 0), 0); //off
            }
          }   
          else if (NewMenuVar == 6)
          {
            OzOled.setCursorXY(0,0);   
            OzOled.printString(" NEOPIXEL ");
            OzOled.setCursorXY(0,2);   
            OzOled.printString(" RAINBOW ");
            if (newState == LOW){
              colorWipe(strip.Color(0, 0, 0), 0);    // Black/off
              rainbow(20);
            }
            else {
              colorWipe(strip.Color(0, 0, 0), 0); //off
            }
          }
          else if (NewMenuVar == 7)
          {
            OzOled.setCursorXY(0,0);   
            OzOled.printString(" NEOPIXEL ");
            OzOled.setCursorXY(0,2);   
            OzOled.printString(" RAINBOW CYCLE ");
            if (newState == LOW){
              colorWipe(strip.Color(0, 0, 0), 0);    // Black/off
              rainbowCycle(20);
            }
            else {
              colorWipe(strip.Color(0, 0, 0), 0); //off
            }
          }  
          else if (NewMenuVar == 8)
          {
            OzOled.setCursorXY(0,0);   
            OzOled.printString(" NEOPIXEL ");
            OzOled.setCursorXY(0,2);   
            OzOled.printString(" THEATER CHASE ");
            OzOled.setCursorXY(0,3);   
            OzOled.printString(" RAINBOW ");
            if (newState == LOW){
              colorWipe(strip.Color(0, 0, 0), 0);    // Black/off
              theaterChaseRainbow(50);
            }
            else {
              colorWipe(strip.Color(0, 0, 0), 0); //off
            }
          }
          else if (NewMenuVar == 9)
          {
            //showLightSensor();
            OzOled.setCursorXY(0,0);   
            OzOled.printString(" NEOPIXEL ");
            OzOled.setCursorXY(0,2);   
            OzOled.printString(" SHOW MODE ");
            showMode(1000);
          }                      
           else 
              {
               // OnOffBool1 = 0;
              }  

  //delay(100);        
}

///////////////////////////////////////////////////////////////////////////////////////////////////////////////////

void showLightSensor(){
  lightSensorValue = analogRead(LIGHT_SENSOR_PIN);
    
  OzOled.setCursorXY(0,0);   
  OzOled.printString("LIGHT SENSOR");  
  OzOled.printString("VALUE",0,1.2);  
 //OzOled.setCursorXY(0,2);  
  OzOled.printNumber(long(lightSensorValue), 0, 3); 
  OzOled.printString("    "); 
}

///////////////////////////////////////////////////////////////////////////////////////////////////////////////////

void showBitmap(){
  OzOled.drawBitmap(nasabitmap, 0, 0, 16, 8);
}

///////////////////////////////////////////////////////////////////////////////////////////////////////////////////

void startShow(int i) {
  switch(i){
    case 0: colorWipe(strip.Color(0, 0, 0), 50);    // Black/off
            break;
    case 1: colorWipe(strip.Color(255, 0, 0), 50);  // Red
            break;
    case 2: colorWipe(strip.Color(0, 255, 0), 50);  // Green
            break;
    case 3: colorWipe(strip.Color(0, 0, 255), 50);  // Blue
            break;
    case 4: theaterChase(strip.Color(127, 127, 127), 50); // White
            break;
    case 5: theaterChase(strip.Color(127,   0,   0), 50); // Red
            break;
    case 6: theaterChase(strip.Color(  0,   0, 127), 50); // Blue
            break;
    case 7: rainbow(20);
            break;
    case 8: rainbowCycle(20);
            break;
    case 9: theaterChaseRainbow(50);
            break;
  }
}
///////////////////////////////////////////////////////////////////////////////////////////////////////////////////

// Fill the dots one after the other with a color
void colorWipe(uint32_t c, uint8_t wait) {
  for(uint16_t i=0; i<strip.numPixels(); i++) {
    strip.setPixelColor(i, c);
    strip.show();
    delay(wait);
  }
}

///////////////////////////////////////////////////////////////////////////////////////////////////////////////////

void rainbow(uint8_t wait) {
  uint16_t i, j;

  for(j=0; j<256; j++) {
    for(i=0; i<strip.numPixels(); i++) {
      strip.setPixelColor(i, Wheel((i+j) & 255));
    }
    strip.show();
    delay(wait);
  }
}

///////////////////////////////////////////////////////////////////////////////////////////////////////////////////

// Slightly different, this makes the rainbow equally distributed throughout
void rainbowCycle(uint8_t wait) {
  uint16_t i, j;

  for(j=0; j<256*5; j++) { // 5 cycles of all colors on wheel
    for(i=0; i< strip.numPixels(); i++) {
      strip.setPixelColor(i, Wheel(((i * 256 / strip.numPixels()) + j) & 255));
    }
    strip.show();
    delay(wait);
  }
}

///////////////////////////////////////////////////////////////////////////////////////////////////////////////////

//Theatre-style crawling lights.
void theaterChase(uint32_t c, uint8_t wait) {
  for (int j=0; j<10; j++) {  //do 10 cycles of chasing
    for (int q=0; q < 3; q++) {
      for (int i=0; i < strip.numPixels(); i=i+3) {
        strip.setPixelColor(i+q, c);    //turn every third pixel on
      }
      strip.show();

      delay(wait);

      for (int i=0; i < strip.numPixels(); i=i+3) {
        strip.setPixelColor(i+q, 0);        //turn every third pixel off
      }
    }
  }
}

///////////////////////////////////////////////////////////////////////////////////////////////////////////////////

//Theatre-style crawling lights with rainbow effect
void theaterChaseRainbow(uint8_t wait) {
  for (int j=0; j < 256; j++) {     // cycle all 256 colors in the wheel
    for (int q=0; q < 3; q++) {
      for (int i=0; i < strip.numPixels(); i=i+3) {
        strip.setPixelColor(i+q, Wheel( (i+j) % 255));    //turn every third pixel on
      }
      strip.show();

      delay(wait);

      for (int i=0; i < strip.numPixels(); i=i+3) {
        strip.setPixelColor(i+q, 0);        //turn every third pixel off
      }
    }
  }
}

///////////////////////////////////////////////////////////////////////////////////////////////////////////////////

//Theatre-style crawling lights with rainbow effect
void showMode(uint8_t wait) {
  for (int j=0; j < 256; j++) {     // cycle all 256 colors in the wheel
    for (int q=0; q < 3; q++) {
      for (int i=0; i < strip.numPixels(); i=i+3) {
        strip.setPixelColor(i+q, Wheel( (i+j) % 255));    //turn every third pixel on
      }
      strip.show();

      delay(wait);

      for (int i=0; i < strip.numPixels(); i=i+3) {
        strip.setPixelColor(i+q, 0);        //turn every third pixel off
      }
      delay(wait);
      
    }
  }
}

///////////////////////////////////////////////////////////////////////////////////////////////////////////////////
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
